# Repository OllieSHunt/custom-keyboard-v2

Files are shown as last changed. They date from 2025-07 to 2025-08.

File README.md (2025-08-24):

# Custom Keyboard V2
This repository contains KiCad design files for a home-made custom keyboard.

keyboard photo

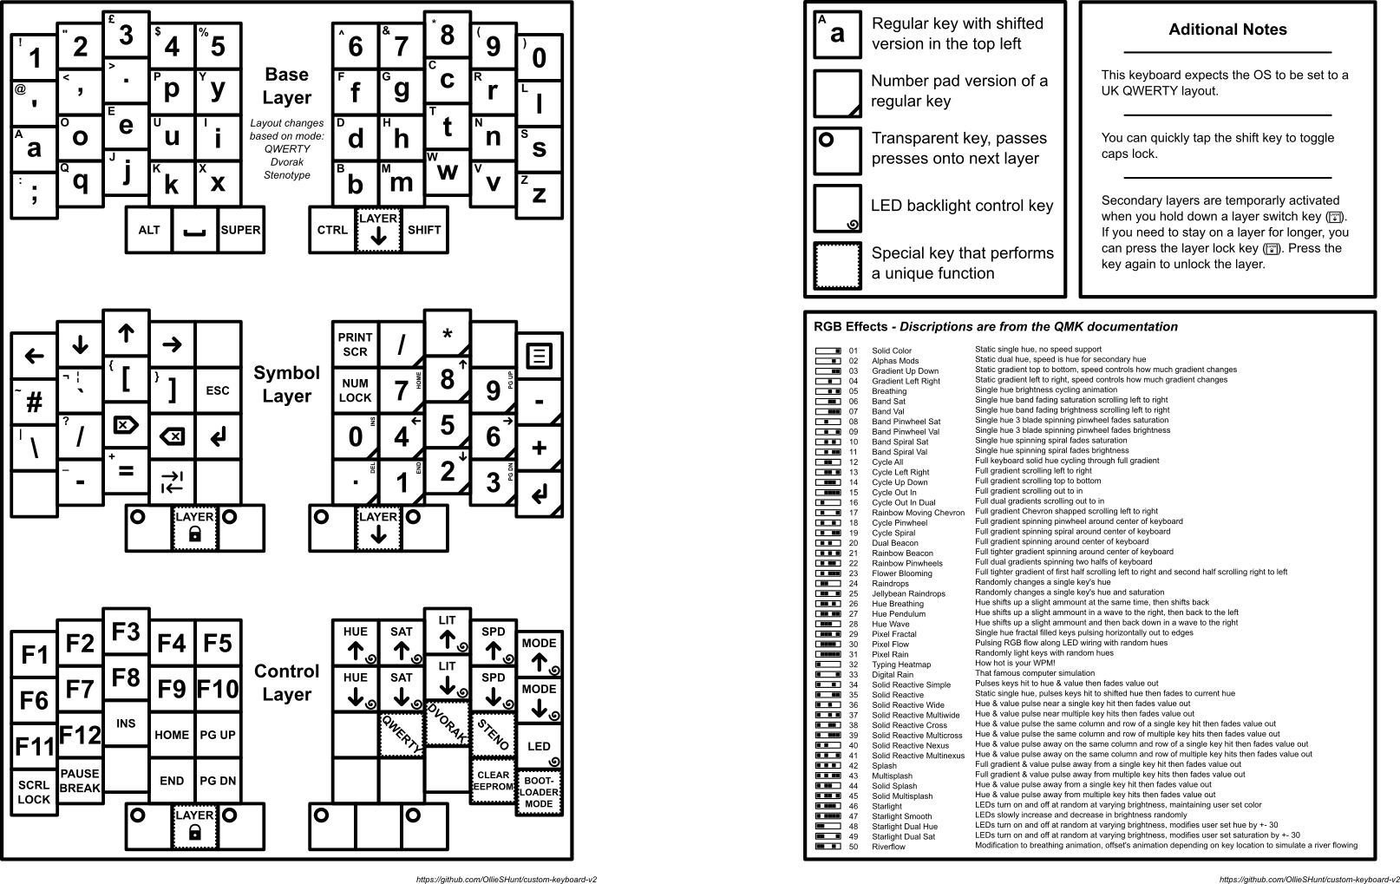
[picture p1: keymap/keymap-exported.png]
keymap layout image


## Current State
***IMPORTANT***: Although the keymap reference sheet (`./keymap/keymap-exported.pdf`) mentions a "Stenotype mode", this is not yet implemented. The rest of the keyboard should be fully functioning though.

## Key Features
- Support for both QWERTY and Dvorak layouts
- Stenography support (**WIP**)
- 128x64 OLED display
  - WPM counter
  - Visual indicators for caps lock, num lock, and scroll lock, as well as layers
- RGB lighting with cool animations

## Repository Layout
- `./circit_board` = KiCad design files
- `./kicad-libs` = Third party libraries that KiCad can use
- `./keymap` = Reference sheet of this keyboard's layout (**NOTE**: `keymap-inkscape.svg` will only show both pages properly when opened with [Inkscape](https://inkscape.org). If you don't want to download Inkscape, please see `keymap-exported.pdf` instead)

## QMK Firmware
This repository just contains the KiCad design files. For the firmware, see [my fork of QMK](https://github.com/OllieSHunt/qmk_firmware).

**IMPORTANT**: Within the fork, the firmware for this keyboard will be located in `dev_branch`, **not** the default `master` branch and will be under the folder `keyboards/custom_keyboard_v2`.

Useful QMK links:
- https://docs.qmk.fm/newbs
- https://docs.qmk.fm/newbs_git_best_practices

## Components List
- Custom circuit board
- Raspberry Pi Pico 1 (without headers)
- SSD1306 based 128x64 OLED display (must be I2C compatible and run of 3V)
- 46 Gateron Low Profile Switch 2.0
- 46 Gateron compatible Low Profile Keycaps
- 46 1N4148W diodes
- 46 WS2812C-2020 LEDs
- Some stick-on silicone feet (I used 5mm tall ones)

## KiCad Libraries Used
- [MX_V2](https://github.com/ai03-2725/MX_V2/tree/main)

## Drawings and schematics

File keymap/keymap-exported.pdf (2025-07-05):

### Layout changes based on mode:

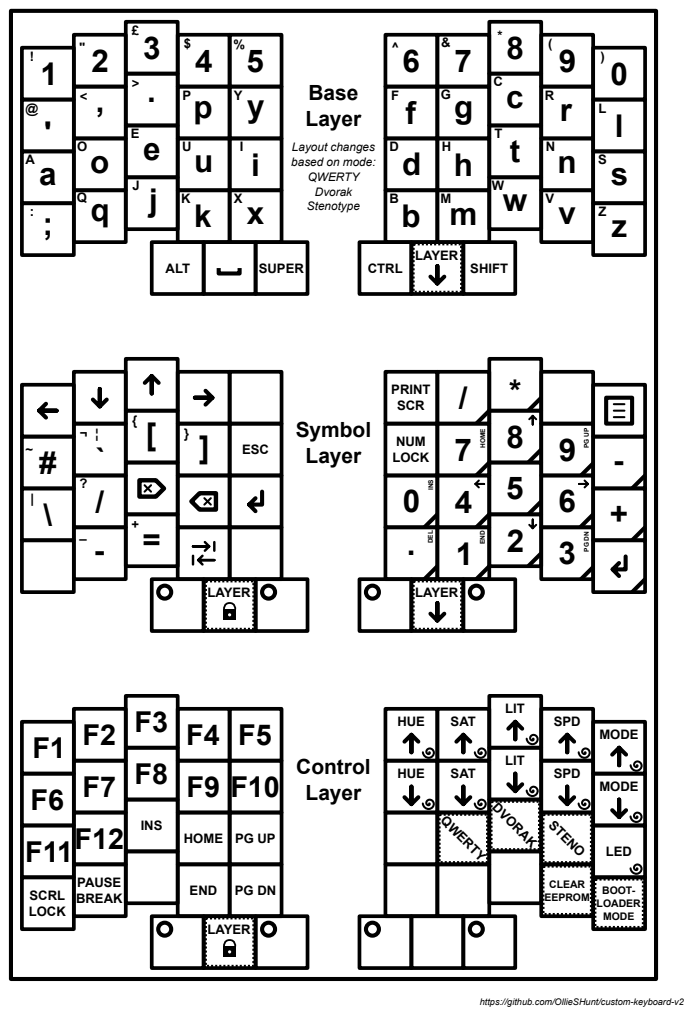
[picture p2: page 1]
QWERTY Dvorak Stenotype; ALT; ESC; PRINT SCR; HUE; SAT; LIT; SPD; QWERTY; DVORAK; STENO; NUM LOCK; INS; HOME; PAUSE BREAK; SUPER; CTRL; Control Layer; Symbol Layer; Base Layer E; SHIFT; LAYER; HOME END; INS DEL; MODE; LED; CLEAR; EEPROM; BOOT-; LOADER MODE

PG DNEND SCRL
LOCK

https://github.com/OllieSHunt/custom-keyboard-v2

A
a | Regular key with shifted version in the top left
| Number pad version of a regular key
| Transparent key, passes presses onto next layer
| LED backlight control key
| Special key that performs a unique function

LAYER

LAYER

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
Solid Color
Alphas Mods
Gradient Up Down
Gradient Left Right
Breathing
Band Sat
Band Val
Band Pinwheel Sat
Band Pinwheel Val
Band Spiral Sat
Band Spiral Val
Cycle All
Cycle Left Right
Cycle Up Down
Cycle Out In
Cycle Out In Dual
Rainbow Moving Chevron
Cycle Pinwheel
Cycle Spiral
Dual Beacon
Rainbow Beacon
Rainbow Pinwheels
Flower Blooming
Raindrops
Jellybean Raindrops
Hue Breathing
Hue Pendulum
Hue Wave
Pixel Fractal
Pixel Flow
Pixel Rain
Typing Heatmap
Digital Rain
Solid Reactive Simple
Solid Reactive
Solid Reactive Wide
Solid Reactive Multiwide
Solid Reactive Cross
Solid Reactive Multicross
Solid Reactive Nexus
Solid Reactive Multinexus
Splash
Multisplash
Solid Splash
Solid Multisplash
Starlight
Starlight Smooth
Starlight Dual Hue
Starlight Dual Sat
Riverflow

## RGB Effects - Discriptions are from the QMK documentation

## This keyboard expects the OS to be set to a

UK QWERTY layout.

# Aditional Notes

## You can quickly tap the shift key to toggle

caps lock.

Static single hue, no speed support
Static dual hue, speed is hue for secondary hue
Static gradient top to bottom, speed controls how much gradient changes Static gradient left to right, speed controls how much gradient changes Single hue brightness cycling animation
Single hue band fading saturation scrolling left to right
Single hue band fading brightness scrolling left to right
Single hue 3 blade spinning pinwheel fades saturation Single hue 3 blade spinning pinwheel fades brightness Single hue spinning spiral fades saturation
Single hue spinning spiral fades brightness
Full keyboard solid hue cycling through full gradient Full gradient scrolling left to right
Full gradient scrolling top to bottom
Full gradient scrolling out to in
Full dual gradients scrolling out to in
Full gradient Chevron shapped scrolling left to right
Full gradient spinning pinwheel around center of keyboard Full gradient spinning spiral around center of keyboard Full gradient spinning around center of keyboard
Full tighter gradient spinning around center of keyboard
Full dual gradients spinning two halfs of keyboard
Full tighter gradient of first half scrolling left to right and second half scrolling right to left Randomly changes a single key's hue
Randomly changes a single key's hue and saturation
Hue shifts up a slight ammount at the same time, then shifts back
Hue shifts up a slight ammount in a wave to the right, then back to the left Hue shifts up a slight ammount and then back down in a wave to the right Single hue fractal filled keys pulsing horizontally out to edges
Pulsing RGB flow along LED wiring with random hues
Randomly light keys with random hues
How hot is your WPM!
That famous computer simulation
Pulses keys hit to hue & value then fades value out
Static single hue, pulses keys hit to shifted hue then fades to current hue
Hue & value pulse near a single key hit then fades value out
Hue & value pulse near multiple key hits then fades value out
Hue & value pulse the same column and row of a single key hit then fades value out
Hue & value pulse the same column and row of multiple key hits then fades value out
Hue & value pulse away on the same column and row of a single key hit then fades value out Hue & value pulse away on the same column and row of multiple key hits then fades value out Full gradient & value pulse away from a single key hit then fades value out
Full gradient & value pulse away from multiple key hits then fades value out
Hue & value pulse away from a single key hit then fades value out
Hue & value pulse away from multiple key hits then fades value out
LEDs turn on and off at random at varying brightness, maintaining user set color
LEDs slowly increase and decrease in brightness randomly
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

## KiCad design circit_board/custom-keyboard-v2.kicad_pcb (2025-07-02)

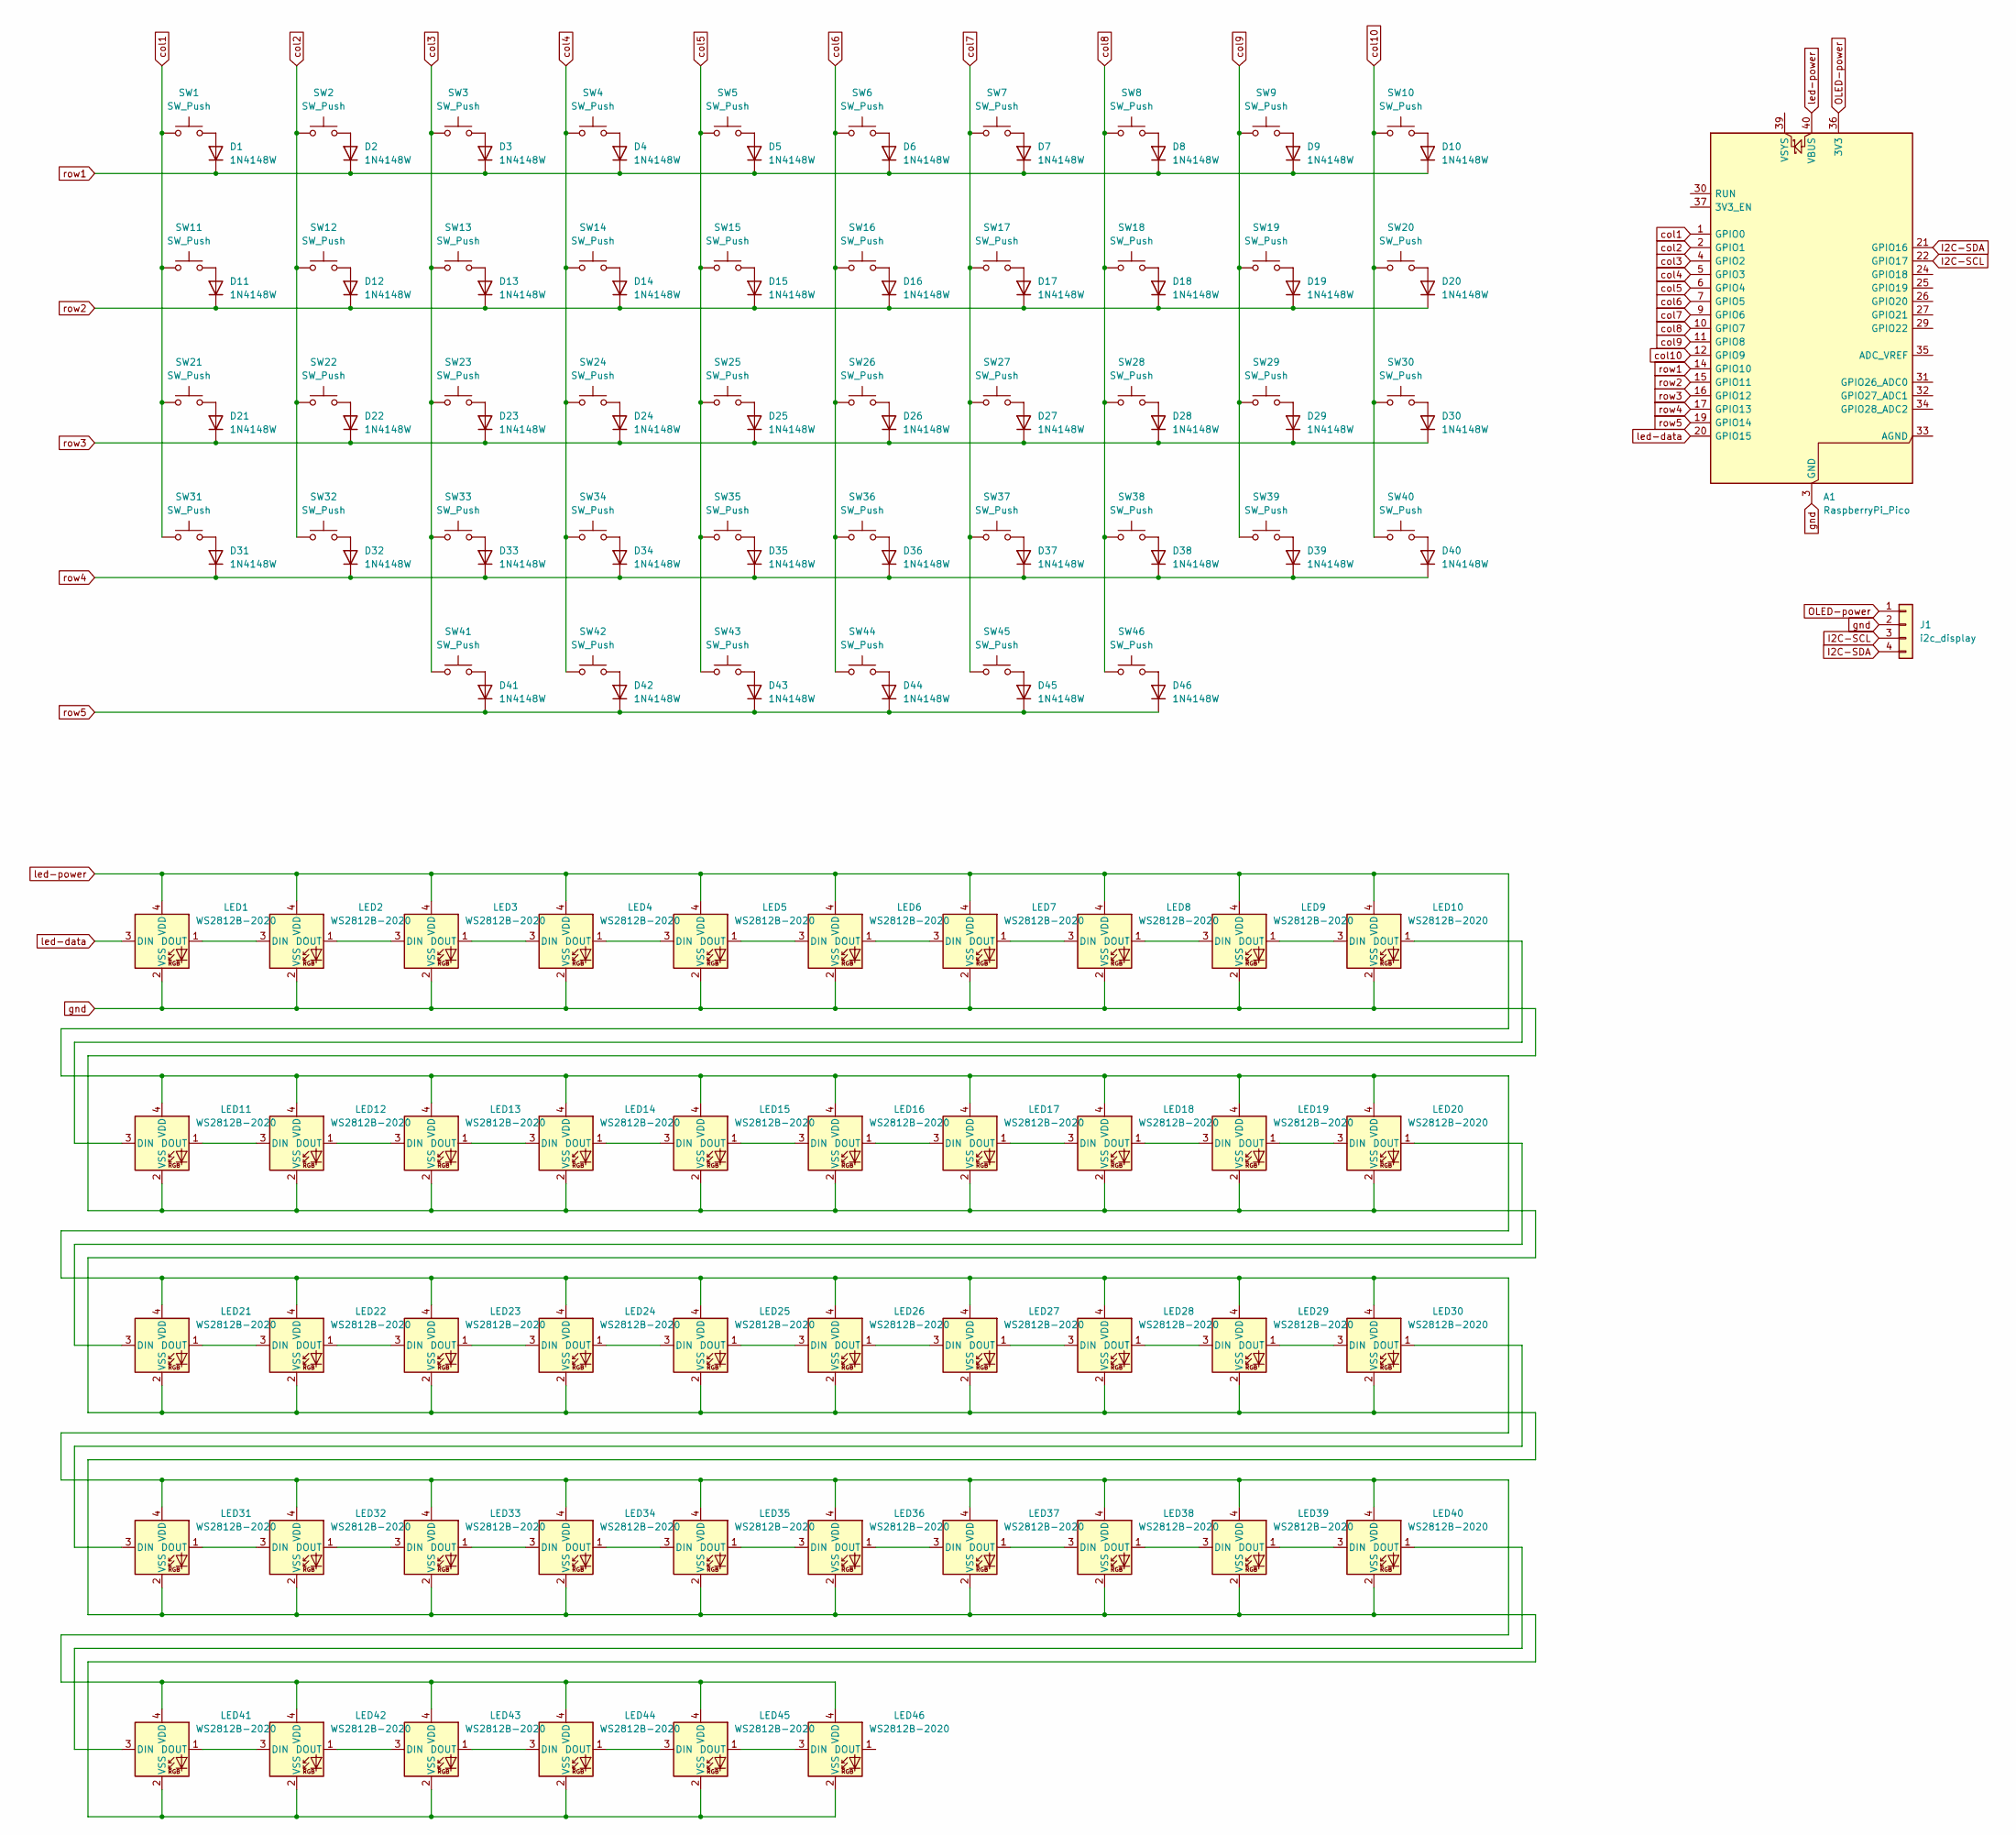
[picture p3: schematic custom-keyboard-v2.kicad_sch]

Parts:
A1: RaspberryPi_Pico; RaspberryPi_Pico_Common_SMD
D1, D2, D3, D4, D5, D6, D7, D8, D9, D10, D11, D12, D13, D14, D15, D16, D17, D18, D19, D20, D21, D22, D23, D24, D25, D26, D27, D28, D29, D30, D31, D32, D33, D34, D35, D36, D37, D38, D39, D40, D41, D42, D43, D44, D45, D46: 1N4148W; D_SOD-123
J1: i2c_display; PinHeader_1x04_P2.54mm_Vertical
LED1, LED2, LED3, LED4, LED5, LED6, LED7, LED8, LED9, LED10, LED11, LED12, LED13, LED14, LED15, LED16, LED17, LED18, LED19, LED20, LED21, LED22, LED23, LED24, LED25, LED26, LED27, LED28, LED29, LED30, LED31, LED32, LED33, LED34, LED35, LED36, LED37, LED38, LED39, LED40, LED41, LED42, LED43, LED44, LED45, LED46: WS2812B-2020; LED_WS2812B-2020_PLCC4_2.0x2.0mm
SW1, SW2, SW3, SW4, SW5, SW6, SW7, SW8, SW9, SW10, SW11, SW12, SW13, SW14, SW15, SW16, SW17, SW18, SW19, SW20, SW21, SW22, SW23, SW24, SW25, SW26, SW27, SW28, SW29, SW30, SW31, SW32, SW33, SW34, SW35, SW36, SW37, SW38, SW39, SW40, SW41, SW42, SW43, SW44, SW45, SW46: SW_Push; Gateron-KS33-Solderable-Template

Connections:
I2C-SCL: A1.22 (GPIO17), J1.3
I2C-SDA: A1.21 (GPIO16), J1.4
unnamed: D1.2 (A), SW1.2
unnamed: D2.2 (A), SW2.2
unnamed: D3.2 (A), SW3.2
unnamed: D4.2 (A), SW4.2
unnamed: D5.2 (A), SW5.2
unnamed: D6.2 (A), SW6.2
unnamed: D7.2 (A), SW7.2
unnamed: D8.2 (A), SW8.2
unnamed: D9.2 (A), SW9.2
unnamed: D10.2 (A), SW10.2
unnamed: D11.2 (A), SW11.2
unnamed: D12.2 (A), SW12.2
unnamed: D13.2 (A), SW13.2
unnamed: D14.2 (A), SW14.2
unnamed: D15.2 (A), SW15.2
unnamed: D16.2 (A), SW16.2
unnamed: D17.2 (A), SW17.2
unnamed: D18.2 (A), SW18.2
unnamed: D19.2 (A), SW19.2
unnamed: D20.2 (A), SW20.2
unnamed: D21.2 (A), SW21.2
unnamed: D22.2 (A), SW22.2
unnamed: D23.2 (A), SW23.2
unnamed: D24.2 (A), SW24.2
unnamed: D25.2 (A), SW25.2
unnamed: D26.2 (A), SW26.2
unnamed: D27.2 (A), SW27.2
unnamed: D28.2 (A), SW28.2
unnamed: D29.2 (A), SW29.2
unnamed: D30.2 (A), SW30.2
unnamed: D31.2 (A), SW31.2
unnamed: D32.2 (A), SW32.2
unnamed: D33.2 (A), SW33.2
unnamed: D34.2 (A), SW34.2
unnamed: D35.2 (A), SW35.2
unnamed: D36.2 (A), SW36.2
unnamed: D37.2 (A), SW37.2
unnamed: D38.2 (A), SW38.2
unnamed: D39.2 (A), SW39.2
unnamed: D40.2 (A), SW40.2
unnamed: D41.2 (A), SW41.2
unnamed: D42.2 (A), SW42.2
unnamed: D43.2 (A), SW43.2
unnamed: D44.2 (A), SW44.2
unnamed: D45.2 (A), SW45.2
unnamed: D46.2 (A), SW46.2
unnamed: LED1.1 (DOUT), LED2.3 (DIN)
unnamed: LED2.1 (DOUT), LED3.3 (DIN)
unnamed: LED3.1 (DOUT), LED4.3 (DIN)
unnamed: LED4.1 (DOUT), LED5.3 (DIN)
unnamed: LED5.1 (DOUT), LED6.3 (DIN)
unnamed: LED6.1 (DOUT), LED7.3 (DIN)
unnamed: LED7.1 (DOUT), LED8.3 (DIN)
unnamed: LED8.1 (DOUT), LED9.3 (DIN)
unnamed: LED9.1 (DOUT), LED10.3 (DIN)
unnamed: LED10.1 (DOUT), LED11.3 (DIN)
unnamed: LED11.1 (DOUT), LED12.3 (DIN)
unnamed: LED12.1 (DOUT), LED13.3 (DIN)
unnamed: LED13.1 (DOUT), LED14.3 (DIN)
unnamed: LED14.1 (DOUT), LED15.3 (DIN)
unnamed: LED15.1 (DOUT), LED16.3 (DIN)
unnamed: LED16.1 (DOUT), LED17.3 (DIN)
unnamed: LED17.1 (DOUT), LED18.3 (DIN)
unnamed: LED18.1 (DOUT), LED19.3 (DIN)
unnamed: LED19.1 (DOUT), LED20.3 (DIN)
unnamed: LED20.1 (DOUT), LED21.3 (DIN)
unnamed: LED21.1 (DOUT), LED22.3 (DIN)
unnamed: LED22.1 (DOUT), LED23.3 (DIN)
unnamed: LED23.1 (DOUT), LED24.3 (DIN)
unnamed: LED24.1 (DOUT), LED25.3 (DIN)
unnamed: LED25.1 (DOUT), LED26.3 (DIN)
unnamed: LED26.1 (DOUT), LED27.3 (DIN)
unnamed: LED27.1 (DOUT), LED28.3 (DIN)
unnamed: LED28.1 (DOUT), LED29.3 (DIN)
unnamed: LED29.1 (DOUT), LED30.3 (DIN)
unnamed: LED30.1 (DOUT), LED31.3 (DIN)
unnamed: LED31.1 (DOUT), LED32.3 (DIN)
unnamed: LED32.1 (DOUT), LED33.3 (DIN)
unnamed: LED33.1 (DOUT), LED34.3 (DIN)
unnamed: LED34.1 (DOUT), LED35.3 (DIN)
unnamed: LED35.1 (DOUT), LED36.3 (DIN)
unnamed: LED36.1 (DOUT), LED37.3 (DIN)
unnamed: LED37.1 (DOUT), LED38.3 (DIN)
unnamed: LED38.1 (DOUT), LED39.3 (DIN)
unnamed: LED39.1 (DOUT), LED40.3 (DIN)
unnamed: LED40.1 (DOUT), LED41.3 (DIN)
unnamed: LED41.1 (DOUT), LED42.3 (DIN)
unnamed: LED42.1 (DOUT), LED43.3 (DIN)
unnamed: LED43.1 (DOUT), LED44.3 (DIN)
unnamed: LED44.1 (DOUT), LED45.3 (DIN)
unnamed: LED45.1 (DOUT), LED46.3 (DIN)
OLED-power: A1.36 (3V3), J1.1
col1: A1.1 (GPIO0), SW1.1, SW11.1, SW21.1, SW31.1
col2: A1.2 (GPIO1), SW2.1, SW12.1, SW22.1, SW32.1
col3: A1.4 (GPIO2), SW3.1, SW13.1, SW23.1, SW33.1, SW41.1
col4: A1.5 (GPIO3), SW4.1, SW14.1, SW24.1, SW34.1, SW42.1
col5: A1.6 (GPIO4), SW5.1, SW15.1, SW25.1, SW35.1, SW43.1
col6: A1.7 (GPIO5), SW6.1, SW16.1, SW26.1, SW36.1, SW44.1
col7: A1.9 (GPIO6), SW7.1, SW17.1, SW27.1, SW37.1, SW45.1
col8: A1.10 (GPIO7), SW8.1, SW18.1, SW28.1, SW38.1, SW46.1
col9: A1.11 (GPIO8), SW9.1, SW19.1, SW29.1, SW39.1
col10: A1.12 (GPIO9), SW10.1, SW20.1, SW30.1, SW40.1
gnd: A1.3 (GND), A1.8 (GND), A1.13 (GND), A1.18 (GND), A1.23 (GND), A1.28 (GND), A1.38 (GND), J1.2, LED1.2 (VSS), LED2.2 (VSS), LED3.2 (VSS), LED4.2 (VSS), LED5.2 (VSS), LED6.2 (VSS), LED7.2 (VSS), LED8.2 (VSS), LED9.2 (VSS), LED10.2 (VSS), LED11.2 (VSS), LED12.2 (VSS), LED13.2 (VSS), LED14.2 (VSS), LED15.2 (VSS), LED16.2 (VSS), LED17.2 (VSS), LED18.2 (VSS), LED19.2 (VSS), LED20.2 (VSS), LED21.2 (VSS), LED22.2 (VSS), LED23.2 (VSS), LED24.2 (VSS), LED25.2 (VSS), LED26.2 (VSS), LED27.2 (VSS), LED28.2 (VSS), LED29.2 (VSS), LED30.2 (VSS), LED31.2 (VSS), LED32.2 (VSS), LED33.2 (VSS), LED34.2 (VSS), LED35.2 (VSS), LED36.2 (VSS), LED37.2 (VSS), LED38.2 (VSS), LED39.2 (VSS), LED40.2 (VSS), LED41.2 (VSS), LED42.2 (VSS), LED43.2 (VSS), LED44.2 (VSS), LED45.2 (VSS), LED46.2 (VSS)
led-data: A1.20 (GPIO15), LED1.3 (DIN)
led-power: A1.40 (VBUS), LED1.4 (VDD), LED2.4 (VDD), LED3.4 (VDD), LED4.4 (VDD), LED5.4 (VDD), LED6.4 (VDD), LED7.4 (VDD), LED8.4 (VDD), LED9.4 (VDD), LED10.4 (VDD), LED11.4 (VDD), LED12.4 (VDD), LED13.4 (VDD), LED14.4 (VDD), LED15.4 (VDD), LED16.4 (VDD), LED17.4 (VDD), LED18.4 (VDD), LED19.4 (VDD), LED20.4 (VDD), LED21.4 (VDD), LED22.4 (VDD), LED23.4 (VDD), LED24.4 (VDD), LED25.4 (VDD), LED26.4 (VDD), LED27.4 (VDD), LED28.4 (VDD), LED29.4 (VDD), LED30.4 (VDD), LED31.4 (VDD), LED32.4 (VDD), LED33.4 (VDD), LED34.4 (VDD), LED35.4 (VDD), LED36.4 (VDD), LED37.4 (VDD), LED38.4 (VDD), LED39.4 (VDD), LED40.4 (VDD), LED41.4 (VDD), LED42.4 (VDD), LED43.4 (VDD), LED44.4 (VDD), LED45.4 (VDD), LED46.4 (VDD)
row1: A1.14 (GPIO10), D1.1 (K), D2.1 (K), D3.1 (K), D4.1 (K), D5.1 (K), D6.1 (K), D7.1 (K), D8.1 (K), D9.1 (K), D10.1 (K)
row2: A1.15 (GPIO11), D11.1 (K), D12.1 (K), D13.1 (K), D14.1 (K), D15.1 (K), D16.1 (K), D17.1 (K), D18.1 (K), D19.1 (K), D20.1 (K)
row3: A1.16 (GPIO12), D21.1 (K), D22.1 (K), D23.1 (K), D24.1 (K), D25.1 (K), D26.1 (K), D27.1 (K), D28.1 (K), D29.1 (K), D30.1 (K)
row4: A1.17 (GPIO13), D31.1 (K), D32.1 (K), D33.1 (K), D34.1 (K), D35.1 (K), D36.1 (K), D37.1 (K), D38.1 (K), D39.1 (K), D40.1 (K)
row5: A1.19 (GPIO14), D41.1 (K), D42.1 (K), D43.1 (K), D44.1 (K), D45.1 (K), D46.1 (K)

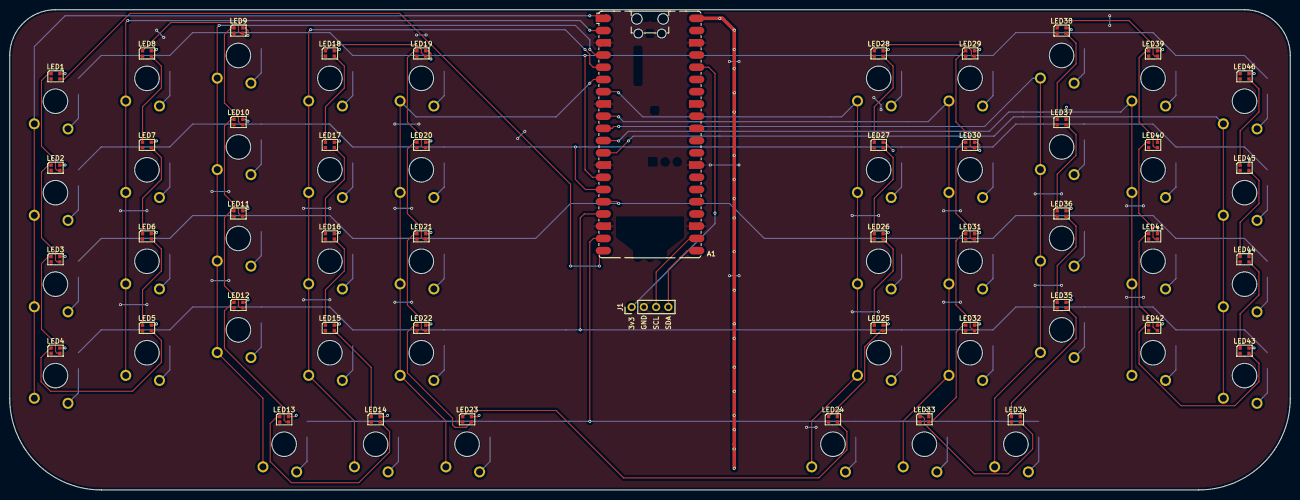
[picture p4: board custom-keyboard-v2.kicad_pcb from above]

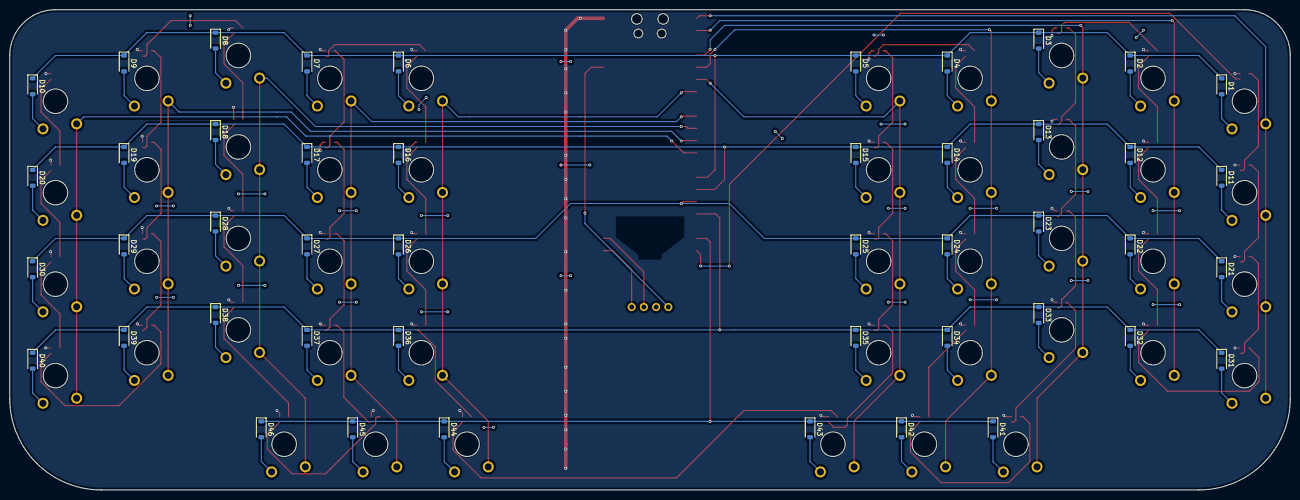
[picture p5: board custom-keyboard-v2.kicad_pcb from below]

Board: 2 copper layers, 266.0 x 99.8 mm, 140 parts (46 on the bottom side), 112 nets.

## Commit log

2025-06-01 Added kicad files
    [custom-keyboard-v2.kicad_pcb, custom-keyboard-v2.kicad_sch]
2025-06-01 Added kicad library for key switches + added a few components into the design
    [custom-keyboard-v2.kicad_pcb, custom-keyboard-v2.kicad_sch]
2025-06-01 Added instructions for centering an LED + gitignore
    [custom-keyboard-v2.kicad_pcb]
2025-06-02 Added keyboard matrix to circit schematic
    [custom-keyboard-v2.kicad_sch]
2025-06-06 Added chain of LEDs intended to go under the keys to the schematic
    [custom-keyboard-v2.kicad_sch]
2025-06-07 LEDs now get power from the Pi Pico's VBUS pin
    [custom-keyboard-v2.kicad_sch]
2025-06-07 Possitioned keys on circitboard with spacing of 19mm (may change later)
    [custom-keyboard-v2.kicad_pcb, custom-keyboard-v2.kicad_sch]
2025-06-10 Positioned dioes on circit board
    [custom-keyboard-v2.kicad_pcb]
2025-06-11 Added vertical offset to keys
    [custom-keyboard-v2.kicad_pcb, custom-keyboard-v2.kicad_sch]
2025-06-11 Added edge cuts + repositioned pi pico
    [custom-keyboard-v2.kicad_pcb]
2025-06-11 Positioned the LEDs on the PCB
    [custom-keyboard-v2.kicad_pcb]
2025-06-11 Added I2C OLED display
    [custom-keyboard-v2.kicad_pcb, custom-keyboard-v2.kicad_sch]
2025-06-12 Began wiring the keyboard matrix, got distracted by 3v -> 5v converters
    [custom-keyboard-v2.kicad_pcb]
2025-06-12 Added 3V -> 5V converter for LED data line
    [custom-keyboard-v2.kicad_pcb, custom-keyboard-v2.kicad_sch]
2025-06-12 Swaped 3V -> 5V convert from through-hole to SMT pads
    [custom-keyboard-v2.kicad_pcb]
2025-06-12 Key switch matrix fully routed
    [custom-keyboard-v2.kicad_pcb]
2025-06-12 Added ground plane
    [custom-keyboard-v2.kicad_pcb]
2025-06-13 Wired up the OLED display
    [custom-keyboard-v2.kicad_pcb]
2025-06-13 Connected LED chain data pins
    [custom-keyboard-v2.kicad_pcb]
2025-06-13 Powered LEDs by flooding the back layer with copper
    [custom-keyboard-v2.kicad_pcb]
2025-06-13 Increased silkscreen line thickness (as per jlcdfm.com's recomendation)
    [custom-keyboard-v2.kicad_pcb]
2025-06-14 Improved gitignore
    https://github.com/github/gitignore/blob/main/KiCad.gitignore
2025-07-02 Removed 3.3V to 5V converter from the LED input
    This turned out to be unnecessary after getting the circit board printed
    [custom-keyboard-v2.kicad_pcb, custom-keyboard-v2.kicad_sch]
